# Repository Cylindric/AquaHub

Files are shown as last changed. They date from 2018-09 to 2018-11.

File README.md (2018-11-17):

# AquaHub
FOSSA Status (https://app.fossa.io/projects/git%2Bgithub.com%2FCylindric%2FAquaHub?ref=badge_shield)


# Key Components

## Hardware

The electronic designs are all made using [KiCad](http://kicad-pcb.org).

The actual KiCad project files are [here](Hardware/AquaHub/).

Rendered output (schematic and board PDFs, gerbers and bom) are [here](Hardware/Output/). (Not always up-to-date with the schematics and boards, so use with caution)

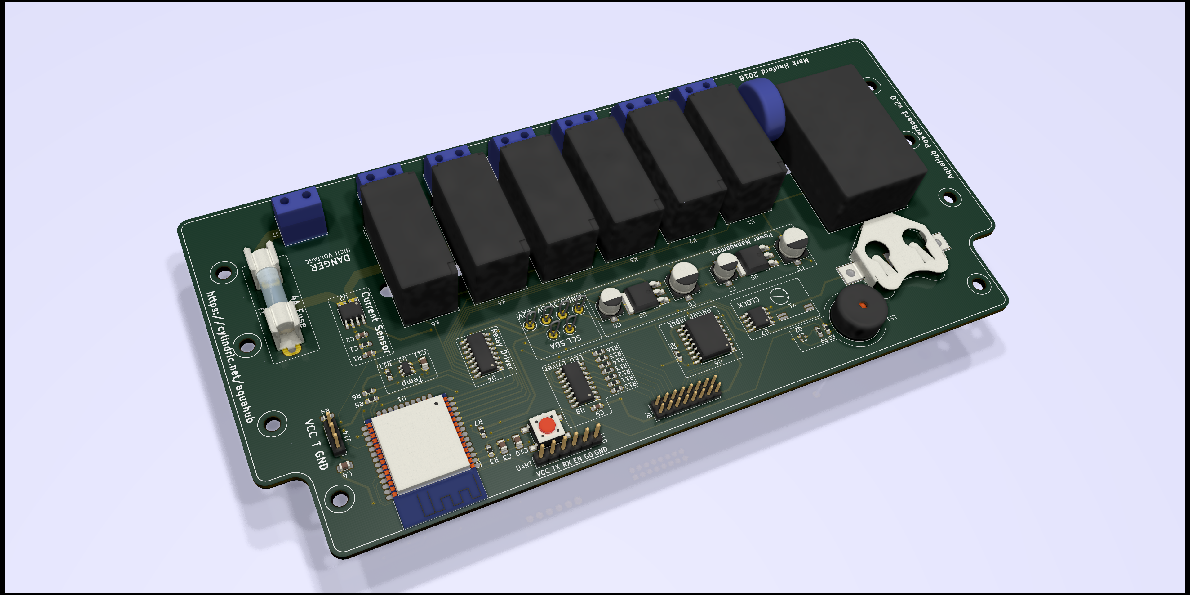
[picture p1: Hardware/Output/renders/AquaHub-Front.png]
Open Hardware


### License

All hardware designs are licensed under the [CERN Open Hardware Licence v1.2](https://www.ohwr.org/licenses/cern-ohl/license_versions/v1.2).

Myriam Ayass, legal adviser of the Knowledge and Technology Transfer Group at CERN and author of the CERN OHL:

> In the spirit of knowledge sharing and dissemination, the CERN Open Hardware Licence (CERN OHL) governs the use, copying, modification and distribution of hardware design documentation, and the manufacture and distribution of products.
> 
> The CERN–OHL is to hardware what the General Public Licence (GPL) is to software. It defines the conditions under which a licensee will be able to use or modify the licensed material. The concept of ‘open-source hardware’ or ‘open hardware’ is not yet as well known or widespread as the free software or open-source software concept. However, it shares the same principles: anyone should be able to see the source (the design documentation in case of hardware), study it, modify it and share it.
> 
> In addition, if modifications are made and distributed, it must be under the same licence conditions – this is the ‘persistent’ nature of the licence, which ensures that the whole community will continue benefiting from improvements, in the sense that everyone will in turn be able to make modifications to these improvements.

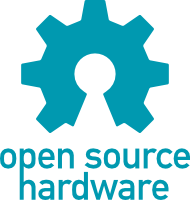
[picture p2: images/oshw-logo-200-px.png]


### Rev 1
- [x] ESP32 module for control and wireless access (Espressif ESP32-WROOM-32D)
- [x] Current Sensing for consumption reporting and equipment failure detection (Melexis MLX91210KDC)
- [x] RTC for power-loss schedule persistence (Maxim DS1307Z)
- [x] Temperature monitoring (DS18B20)
- [x] Audible alarm
- [x] Six switchable mains-level outputs (Fujitsu FTR-F1A)
- [x] Direct mains-powered (Recom RAC04-12SGB)

### Rev 2
- [ ] PCB: selectable low-level power select, for testing from a 12V supply instead of 240V
- [x] PCB: additional sensor for ambient temperature (on-board or external?)
- [ ] PCB: additional input for flow-rate sensor
- [ ] PCB: additional input for pH sensor (might not be feasible without a permanent-immersion sensor?)
- [ ] PCB: LED power indication for ESP
- [x] PCB: Reset button for ESP
- [x] PCB: Test points for probe hooks
- [x] PCB: Change buttons to off-board panel buttons
- [ ] ENCLOSURE: Add a 6-pin socket for programming
- [ ] ENCLOSURE: Switched & fused power inlet receptacle
- [ ] ENCLOSURE: Non-PCB panel buttons - more choice, better buttons
- [ ] ENCLOSURE: Power LED

## Software

### License

All software (firmware) are Copyright 2018 Mark Hanford and licensed under the [Apache License, Version 2.0](http://www.apache.org/licenses/LICENSE-2.0) (the "License");

> You may not use this file except in compliance with the License. You may obtain a copy of the License at
>
> http://www.apache.org/licenses/LICENSE-2.0
>
> Unless required by applicable law or agreed to in writing, software distributed under the License is distributed on an "AS IS" BASIS, WITHOUT WARRANTIES OR CONDITIONS OF ANY KIND, either express or implied.
> See the License for the specific language governing permissions and limitations under the License.

### Rev 1
- [ ] Over-the-air firmware updates
- [ ] Web UI
- [ ] Task Scheduler
- [ ] Temperature-based control
- [ ] Temperature alarm
- [ ] Pump-fail alarm
- [ ] WiFi config

# Hardware Build

A Mouser project with some of the components listed in detail is available here: [AquaHub At Mouser](https://www.mouser.com/ProjectManager/ProjectDetail.aspx?AccessID=329311b4a5). Not always updated with the current BOM from the schematic, and parts change so may be unavailable. CHECK THE SCHEMATIC.

## Datasheets

* [Espressif ESP32 WROOM 32D](https://www.espressif.com/sites/default/files/documentation/esp32-wroom-32d_esp32-wroom-32u_datasheet_en.pdf)
* [Recom 5v Regulator](https://www.recom-power.com/pdf/Innoline/R-78Exx-0.5.pdf)
* [Diodes 3.3V Regulator](http://www.diodes.com/datasheets/AP1117.pdf)
* [2SC1815 Transistor](https://media.digikey.com/pdf/Data%20Sheets/Toshiba%20PDFs/2SC1815.pdf)
* [Maxim I²C RTC](https://datasheets.maximintegrated.com/en/ds/DS1307.pdf)
* [TI I²C IO Expander](http://www.ti.com/lit/ds/symlink/tca9534.pdf)
* [TI I²C LED Driver](http://www.ti.com/lit/ds/symlink/tpic2810.pdf)

## References

* DS18B20 temperature - [ESP32 With Multiple DS18B20 Sensors](https://randomnerdtutorials.com/esp32-with-multiple-ds18b20-temperature-sensors/)

# Attribution

* Fish icon is from [iconsDB](https://www.iconsdb.com/custom-color/fish-3-icon.html); Creative Commons Attribution-NoDerivs 3.0.

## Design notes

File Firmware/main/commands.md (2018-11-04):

# Serial Commands

## relay

* relay on n
* relay off n

## time

* time get
* time set

## i2c

* i2c

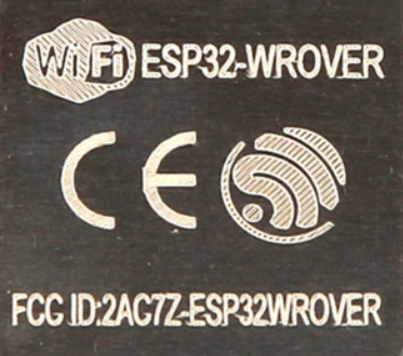
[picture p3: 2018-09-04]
Hardware/AquaHub/Models/esp32-wrover.PNG

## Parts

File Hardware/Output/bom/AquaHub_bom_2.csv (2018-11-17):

Component | Description | Part | References | Value | Footprint | Quantity Per PCB | Datasheet | Mouser | Vendor | Farnell | RS
1 | b'' | b'Battery_Cell-Device' | b'BT1' | b'CR2032' | b'BatteryHolder_Multicomp_BC-2001_1x2032' | b'1' | b'~' | b'534-1058' | b'Mouser' | b'' | b''
2 | b'' | b'C_Small-Device' | b'C4 C10 C11' | b'0.1uF' | b'C_0805_2012Metric_Pad1.15x1.40mm_HandSolder' | b'3' | b'~' | b'TAJB106K006SNJ' | b'Mouser' | b'' | b''
3 | b'' | b'C-Device' | b'C1' | b'100nF' | b'C_0603_1608Metric_Pad1.05x0.95mm_HandSolder' | b'1' | b'~' | b'710-885012206071' | b'Mouser' | b'CA07658' | b''
4 | b'Unpolarized capacitor, small symbol' | b'C_Small' | b'C9' | b'100nF' | b'C_0603_1608Metric_Pad1.05x0.95mm_HandSolder' | b'1' | b'~' | b'710-885012206071' | b'' | b'CA07658' | b''
5 | b'' | b'C-Device' | b'C2' | b'10nF' | b'C_0603_1608Metric_Pad1.05x0.95mm_HandSolder' | b'1' | b'~' | b'VJ0603A102GXAPW1BC' | b'Mouser' | b'' | b''
6 | b'' | b'C_Small-Device' | b'C3' | b'10uF' | b'C_0805_2012Metric_Pad1.15x1.40mm_HandSolder' | b'1' | b'~' | b'TAJB106K006SNJ' | b'Mouser' | b'' | b''
7 | b'' | b'CP_Small-Device' | b'C5 C6' | b'10uF' | b'CP_Elec_6.3x5.4_Nichicon' | b'2' | b'~' | b'UWX1H100MCL1GB' | b'Mouser' | b'CA07886' | b''
8 | b'' | b'CP_Small-Device' | b'C7 C8' | b'4.7uF' | b'CP_Elec_5x5.4' | b'2' | b'~' | b'UWX1H4R7MCL1GB' | b'Mouser' | b'' | b''
9 | b'' | b'Fuse-Device' | b'F1' | b'4A' | b'Fuseholder_Glass_5mmx20mm' | b'1' | b'~' | b'534-3512' | b'Mouser' | b'' | b''
10 | b'Generic connector, single row, 01x15, script generated (kicad-library-utils/schlib/autogen/connector/)' | b'Conn_01x15_Female' | b'J8' | b'Conn_01x15_Female' | b'PinHeader_2x08_P2.00mm_Vertical' | b'1' | b'https://www.mouser.co.uk/datasheet/2/185/DF51_catalog-1274968.pdf' | b'798-DF51A-16DP-2DSA' | b'' | b'' | b''
11 | b'' | b'Conn_01x03-Connector_Generic' | b'J14' | b'PinHeader3' | b'PinHeader_1x03_P2.54mm_Vertical' | b'1' | b'~' | b'710-61300311121' | b'' | b'' | b''
12 | b'' | b'Conn_01x06-Connector_Generic' | b'J10' | b'PinHeader6' | b'PinHeader_1x06_P2.54mm_Vertical' | b'1' | b'~' | b'710-61300611121' | b'' | b'' | b''
13 | b'' | b'Screw_Terminal_01x02-Connector' | b'J1 J2 J3 J4 J5 J6 J7' | b'Screw_Terminal_01x02' | b'TerminalBlock_Phoenix_PT-1,5-2-5.0-H_1x02_P5.00mm_Horizontal' | b'7' | b'~' | b'1935161' | b'Mouser' | b'' | b''
14 | b'' | b'Fujitsu_FTR-F1A-Relay' | b'K1 K2 K3 K4 K5 K6' | b'5A Relay' | b'Relay_DPST_Fujitsu_FTR-F1A' | b'6' | b'' | b'FTR-F1AA012V' | b'Mouser' | b'' | b''
15 | b'Crystal speaker/transducer' | b'Speaker_Crystal' | b'LS1' | b'Piezo' | b'Buzzer_TDK_PS1240P02BT_D12.2mm_H6.5mm' | b'1' | b'~' | b'PS1240P02BT' | b'Mouser' | b'' | b''
16 | b'' | b'2SC1815-Transistor_BJT' | b'Q2' | b'2SC4738' | b'SOT-416' | b'1' | b'http://www.semicon.toshiba.co.jp/info/lookup.jsp?pid=2SC4738&lang=en' | b'757-2SC4738-YLF' | b'Mouser' | b'SC06581' | b''
17 | b'Resistor' | b'R' | b'R17' | b'1.5k' | b'R_0603_1608Metric_Pad1.05x0.95mm_HandSolder' | b'1' | b'~' | b'603-RC0603FR-101K5L' | b'Mouser' | b'' | b''
18 | b'' | b'R-Device' | b'R1 R3 R7' | b'10k' | b'R_0603_1608Metric_Pad1.05x0.95mm_HandSolder' | b'3' | b'~' | b'603-RC0603FR-0710KL' | b'Mouser' | b'' | b''
19 | b'' | b'R-Device' | b'R8 R9' | b'1K' | b'R_0603_1608Metric_Pad1.05x0.95mm_HandSolder' | b'2' | b'~' | b'603-RC0603FR-071KL' | b'Mouser' | b'RE07090' | b''
20 | b'' | b'R-Device' | b'R10 R11 R12 R13 R14 R15 R16' | b'330R' | b'R_0603_1608Metric_Pad1.05x0.95mm_HandSolder' | b'7' | b'~' | b'603-RC0603FR-07330RL' | b'Mouser' | b'RE07105' | b''
21 | b'Resistor' | b'R' | b'R2 R4' | b'4.7k' | b'R_0603_1608Metric_Pad1.05x0.95mm_HandSolder' | b'2' | b'~' | b'603-RC0603FR-074K7L' | b'Mouser' | b'' | b''
22 | b'' | b'R-Device' | b'R5 R6' | b'4.7k' | b'R_0603_1608Metric_Pad1.05x0.95mm_HandSolder' | b'2' | b'~' | b'603-RC0603FR-074K7L' | b'Mouser' | b'' | b''
23 | b'' | b'Varistor-Device' | b'RV1' | b'S14MOV' | b'RV_Disc_D15.5mm_W6.1mm_P7.5mm' | b'1' | b'~' | b'B72214P2251K101' | b'Mouser' | b'' | b''
24 | b'' | b'SW_CK_D6R_SPST-Switch' | b'SW7' | b'Reset' | b'SW_SPST_PTS645' | b'1' | b'' | b'611-PTS645SM43SMTR92' | b'Mouser' | b'' | b''
25 | b'' | b'NCP1117-3.3_TO252-Regulator_Linear' | b'U3' | b'1A 3.3V' | b'TO-252-3_TabPin2' | b'1' | b'http://www.diodes.com/datasheets/AP1117.pdf' | b'NCP1117DT33G' | b'Mouser' | b'' | b''
26 | b'' | b'NCP1117-5.0_TO252-Regulator_Linear' | b'U5' | b'1A 5V' | b'TO-252-3_TabPin2' | b'1' | b'https://www.recom-power.com/pdf/Innoline/R-78Exx-0.5.pdf' | b'NCP1117DT50G' | b'Mouser' | b'' | b''
27 | b'' | b'DS1307+-Timer_RTC' | b'U7' | b'DS1307+' | b'SOIC-8_3.9x4.9mm_P1.27mm' | b'1' | b'https://datasheets.maximintegrated.com/en/ds/DS1307.pdf' | b'700-DS1307ZT&R' | b'' | b'' | b''
28 | b'' | b'ESP32-WROOM-32-MCU_Espressif' | b'U1' | b'ESP32-WROOM' | b'Espressif_ESP32_WROOM_32_SMT' | b'1' | b'' | b'ESP32-WROOM-32D' | b'Mouser' | b'' | b''
29 | b'' | b'MLX91210-AquaParts' | b'U2' | b'MLX91210' | b'SOIC-8_3.9x4.9mm_P1.27mm' | b'1' | b'http://www.allegromicro.com/~/media/Files/Datasheets/ACS723-Datasheet.ashx?la=en' | b'MLX91210KDC-CAS-102-SP' | b'Mouser' | b'' | b''
30 | b' Digital Temperature Sensor & Thermal Watchdog, SOIC-8 and VSSOP-8' | b'PCT2075-TSOP6' | b'U9' | b'PCT2075' | b'TSOP-6_1.65x3.05mm_P0.95mm' | b'1' | b'https://www.mouser.co.uk/datasheet/2/302/PCT2075-1127732.pdf' | b'771-PCT2075GVX' | b'' | b'' | b''
31 | b'' | b'TCA9534-Interface_Expansion' | b'U6' | b'TCA9534' | b'SOIC-16W_7.5x10.3mm_P1.27mm' | b'1' | b'http://www.ti.com/lit/ds/symlink/tca9534.pdf' | b'TCA9534DWR' | b'Mouser' | b'' | b''
32 | b'8-bit LED driver with I2C interface' | b'TPIC2810D' | b'U8' | b'TPIC2810D' | b'SOIC-16_3.9x9.9mm_P1.27mm' | b'1' | b'http://www.ti.com/lit/ds/symlink/tpic2810.pdf' | b'595-TPIC2810DR' | b'' | b'' | b'660-7981'
33 | b'' | b'TPL7407LA-AquaParts' | b'U4' | b'TPL7407LADR' | b'SOIC-16_3.9x9.9mm_P1.27mm' | b'1' | b'http://www.ti.com/lit/ds/symlink/tpl7407la.pdf' | b'595-TPL7407LADR' | b'Mouser' | b'' | b''
34 | b'' | b'RAC04-xxGA-Converter_ACDC' | b'V1' | b'4W AC-DC Converter' | b'Converter_ACDC_RECOM_RAC04-xxSGx_THT' | b'1' | b'' | b'RAC04-12SGB' | b'' | b'' | b''
35 | b'Four pin crystal, GND on pins 2 and 3' | b'Crystal_GND23' | b'Y1' | b'32.768KHz' | b'Crystal_SMD_SeikoEpson_MC146-4Pin_6.7x1.5mm_HandSoldering' | b'1' | b'~' | b'732-MC146-32.7KAA0R' | b'' | b'' | b''
Component Groups: | 35
Component Count: | 61
Fitted Components: | 61
Number of PCBs: | 1
Total components: | 61
Schematic Version: | 2
Schematic Date: | 2018-08-28
BoM Date: | b'17/11/2018 01:01:26'
Schematic Source: | b'D:\\AquaHub\\Hardware\\AquaHub\\AquaHub.sch'
KiCad Version: | b'Eeschema (6.0.0-rc1-dev-904-g29e0e6921)'

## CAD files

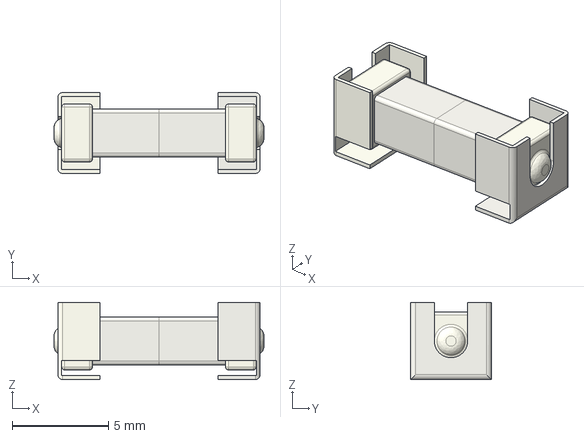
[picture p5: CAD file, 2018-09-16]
Hardware/AquaHub/Models/Fuse.step
10.9 x 4.20 x 4.00 mm

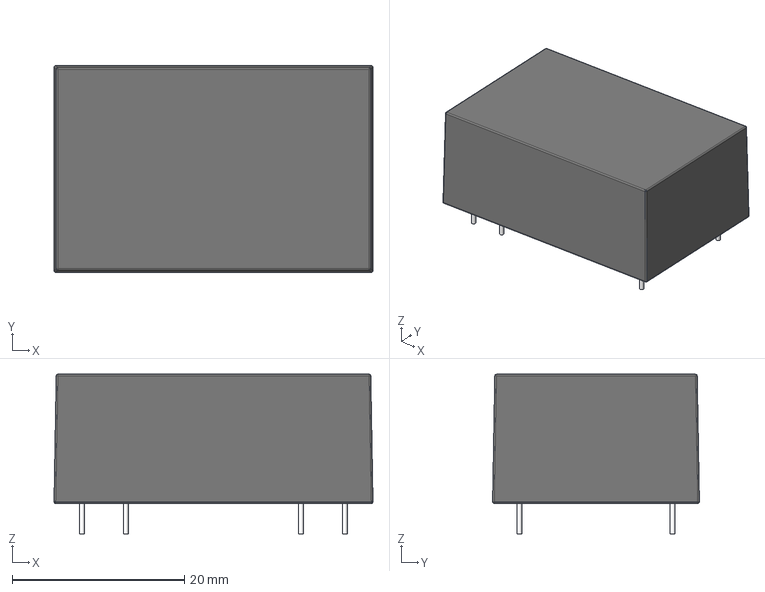
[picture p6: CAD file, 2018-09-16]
Hardware/AquaHub/Models/Recom RAC04-GA.step
37.0 x 24.0 x 18.5 mm

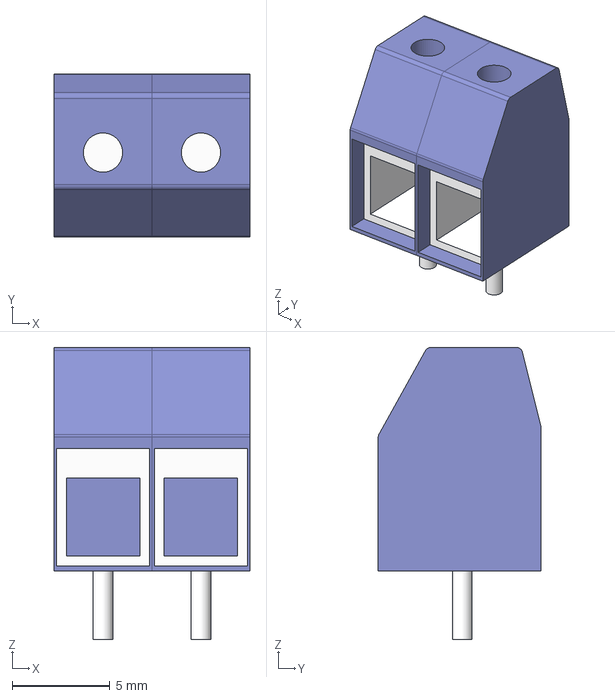
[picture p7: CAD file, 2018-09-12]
Hardware/AquaHub/Models/phoenix_pt-1.5-2.step
10.0 x 8.30 x 14.9 mm
Cage x 2

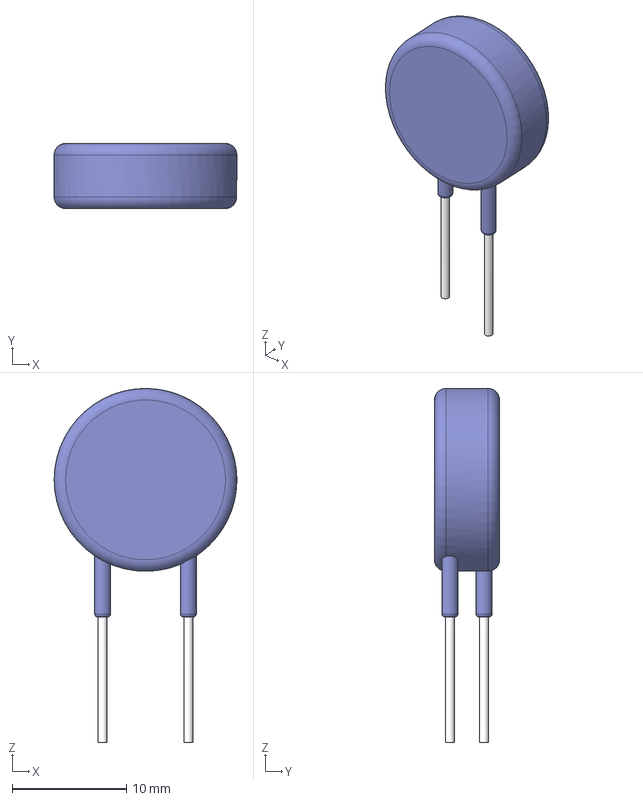
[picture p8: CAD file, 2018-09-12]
Hardware/AquaHub/Models/Varistor.step
16.0 x 5.70 x 31.0 mm

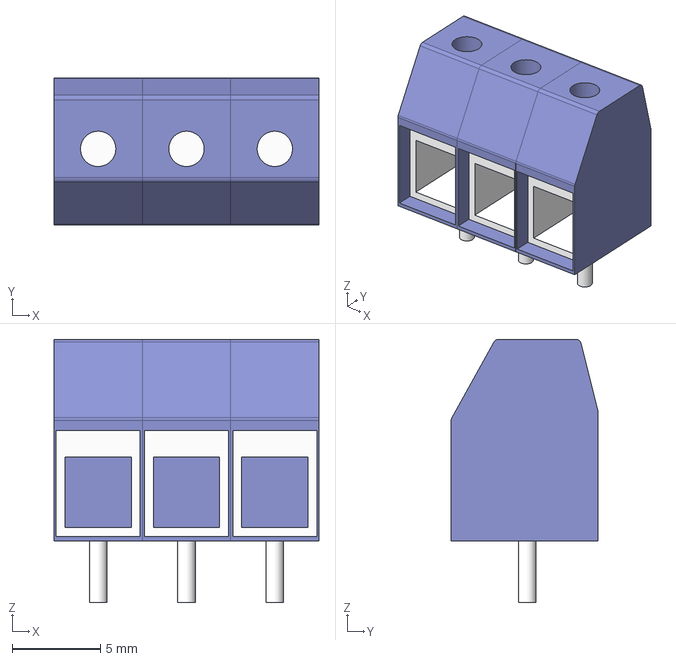
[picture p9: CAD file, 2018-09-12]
Hardware/AquaHub/Models/phoenix_pt-1.5-3.step
15.0 x 8.30 x 14.9 mm
Cage x 3

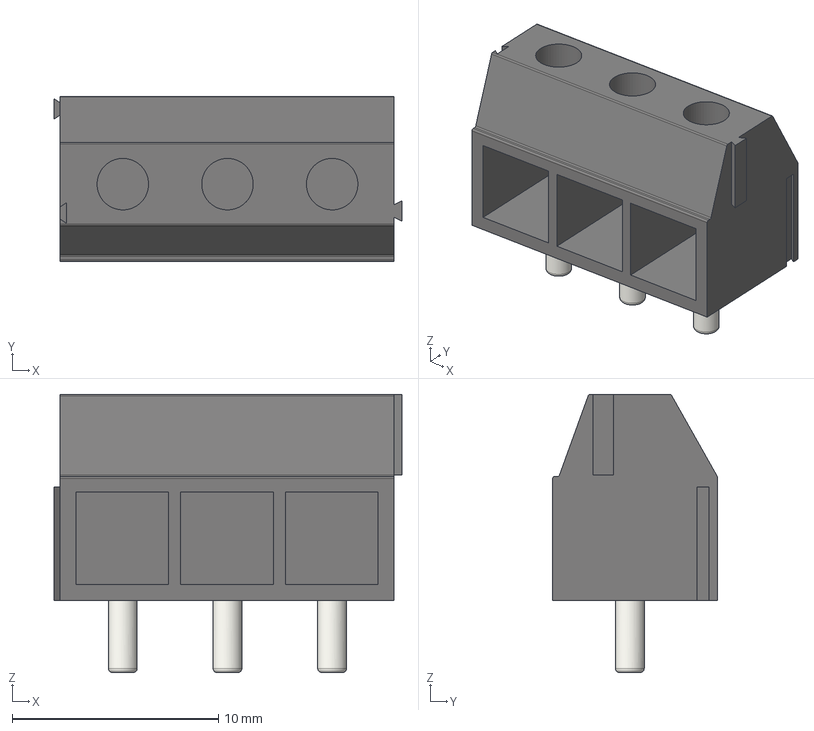
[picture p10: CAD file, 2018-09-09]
Hardware/AquaHub/Models/weidmuller_pm_5_08_3_way.step
16.9 x 8.00 x 13.5 mm

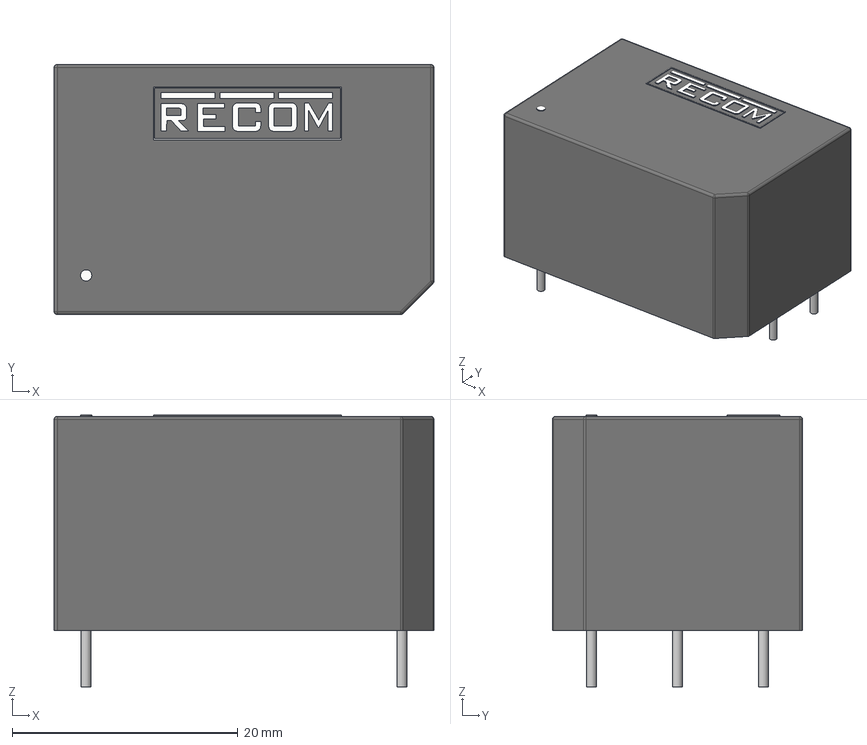
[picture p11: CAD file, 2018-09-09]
Hardware/AquaHub/Models/Converter_ACDC_RECOM_RAC01-xSGB_THT.step
33.7 x 22.2 x 24.1 mm

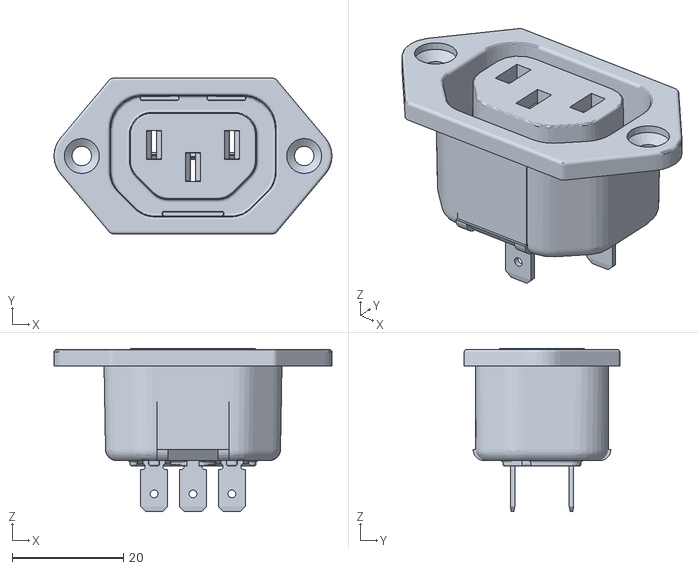
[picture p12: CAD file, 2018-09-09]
Hardware/AquaHub/Models/socket-c13.obj
50.0 x 28.0 x 29.4

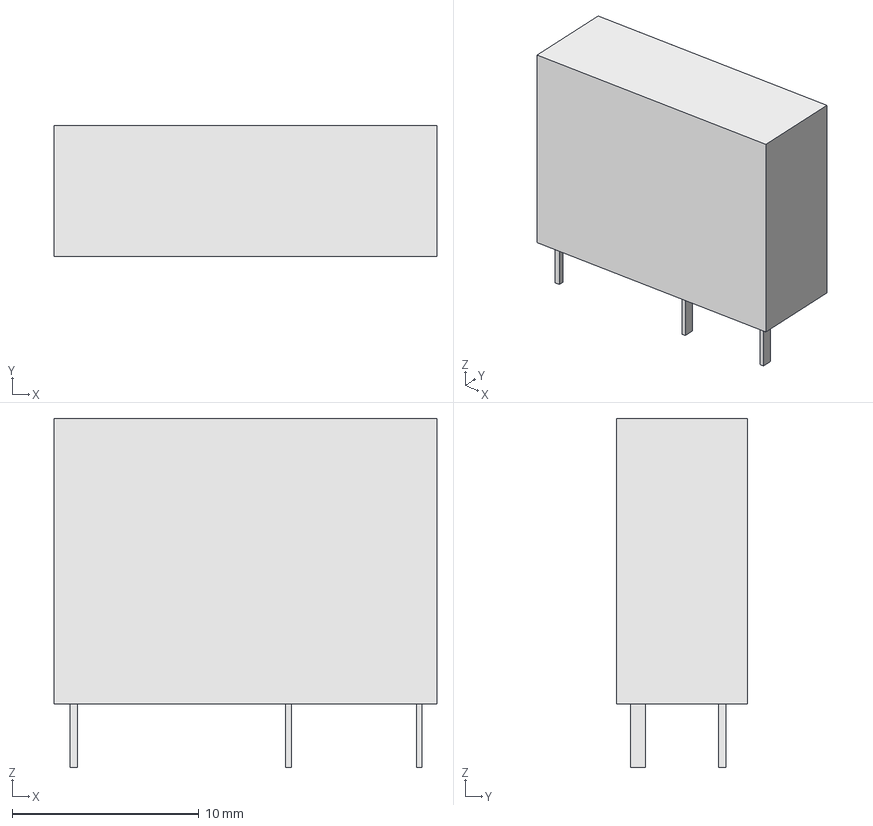
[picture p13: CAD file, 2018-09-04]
Hardware/AquaHub/Models/Relay-HF46F.FCStd
20.5 x 7.00 x 18.7 mm

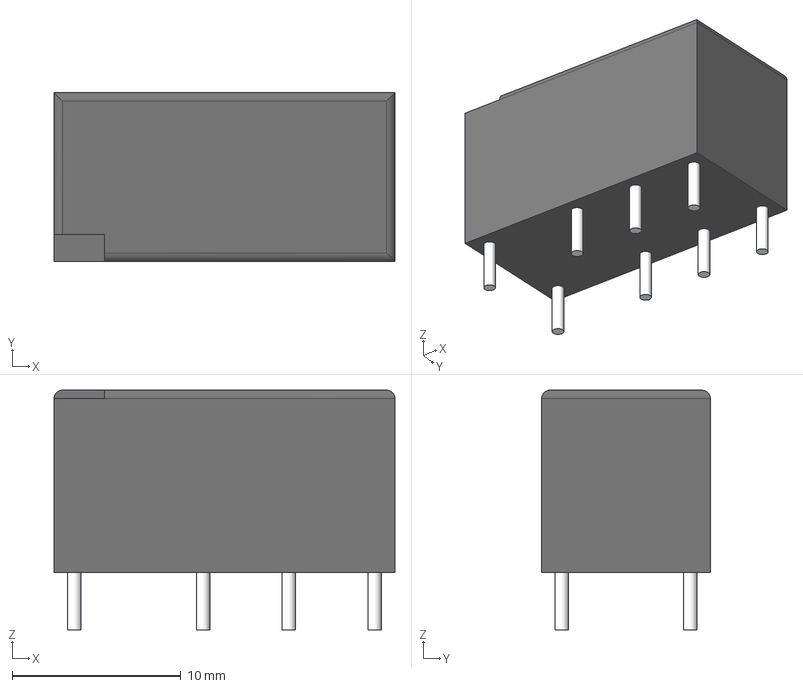
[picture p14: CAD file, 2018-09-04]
Hardware/AquaHub/Models/MT2 Relay.step
20.2 x 10.0 x 14.2 mm

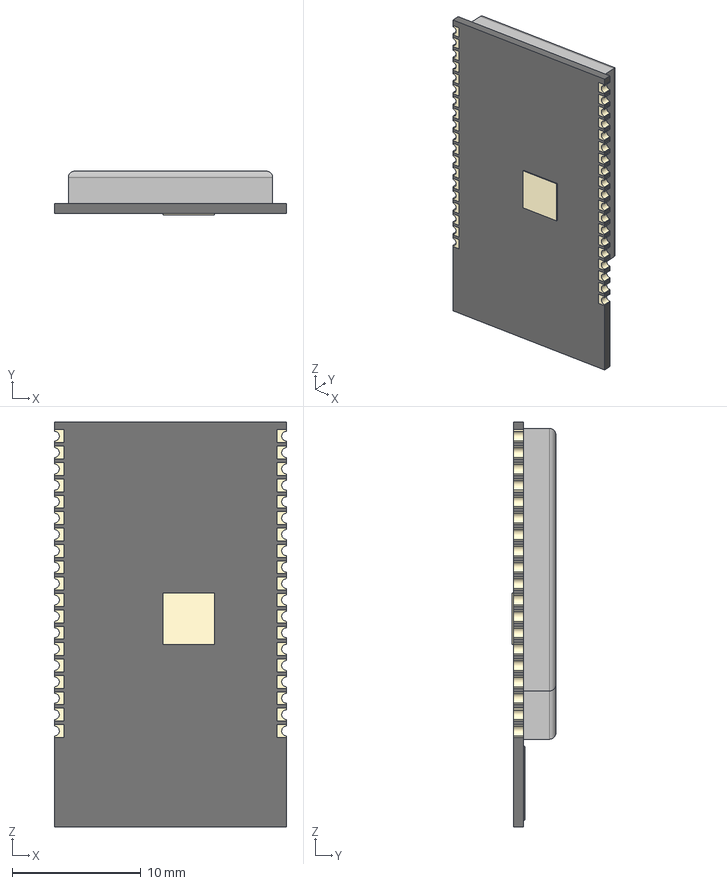
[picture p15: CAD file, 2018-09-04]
Hardware/AquaHub/Models/ES32-WROVER.step
18.0 x 3.40 x 31.4 mm

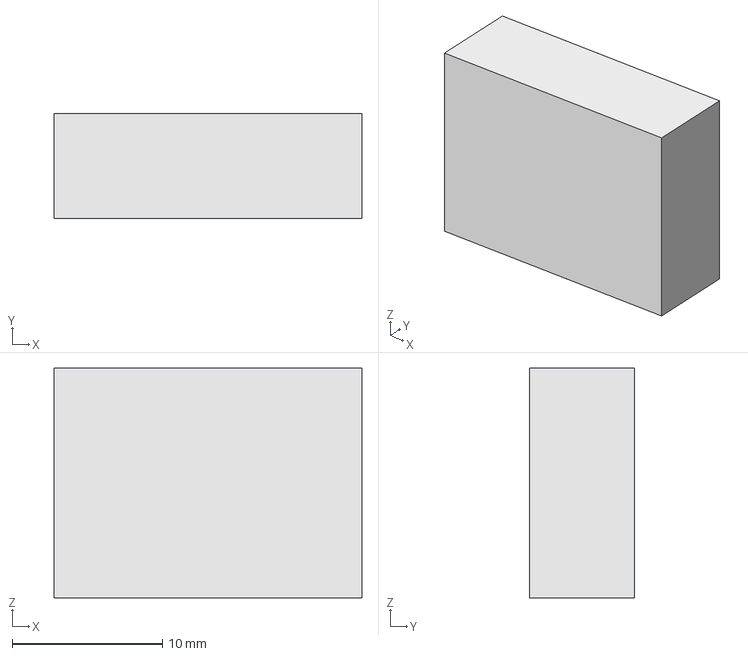
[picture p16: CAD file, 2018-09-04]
Hardware/AquaHub/Models/Cube.step
20.5 x 7.00 x 15.3 mm

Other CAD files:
Hardware/AquaHub/Models/Recom RAC01-GB.step
Hardware/AquaHub/Models/Compound.step
Hardware/AquaHub/Models/Recom_RAC01-GB.step

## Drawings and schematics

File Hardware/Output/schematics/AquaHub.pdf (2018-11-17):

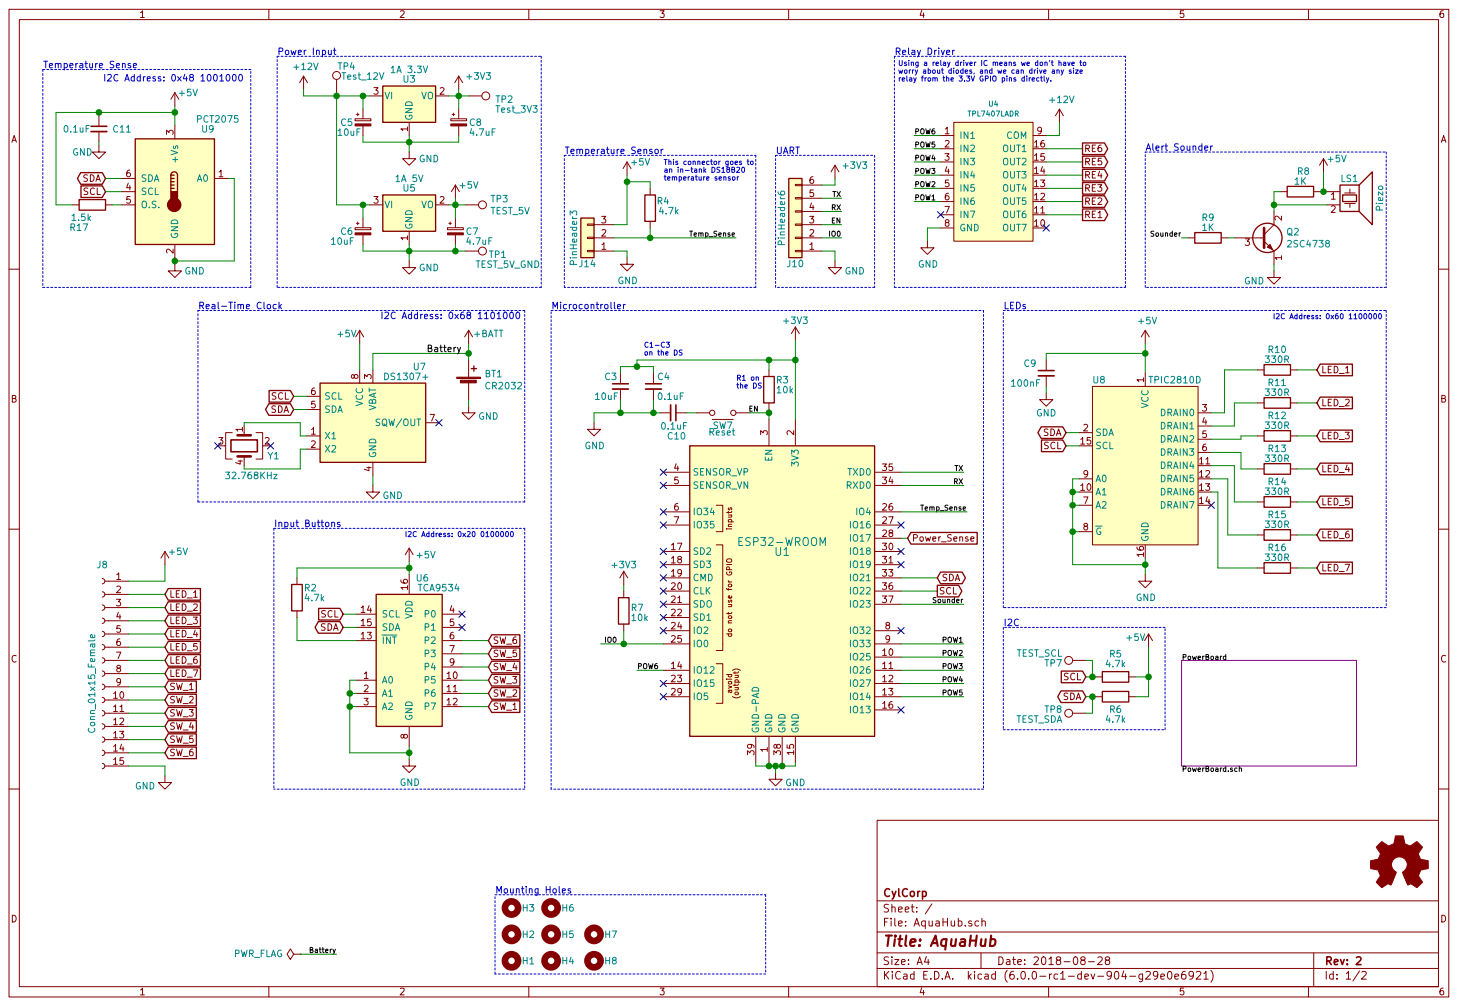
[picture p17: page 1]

Using a relay driver IC means we don't have to worry about diodes, and we can drive any size

Temp_Sense This connector goes to
an in-tank DS18B20

4 SDA 5 SCL 6 SQW/OUT 7 VCC

File: AquaHub.sch Sheet: / CylCorp

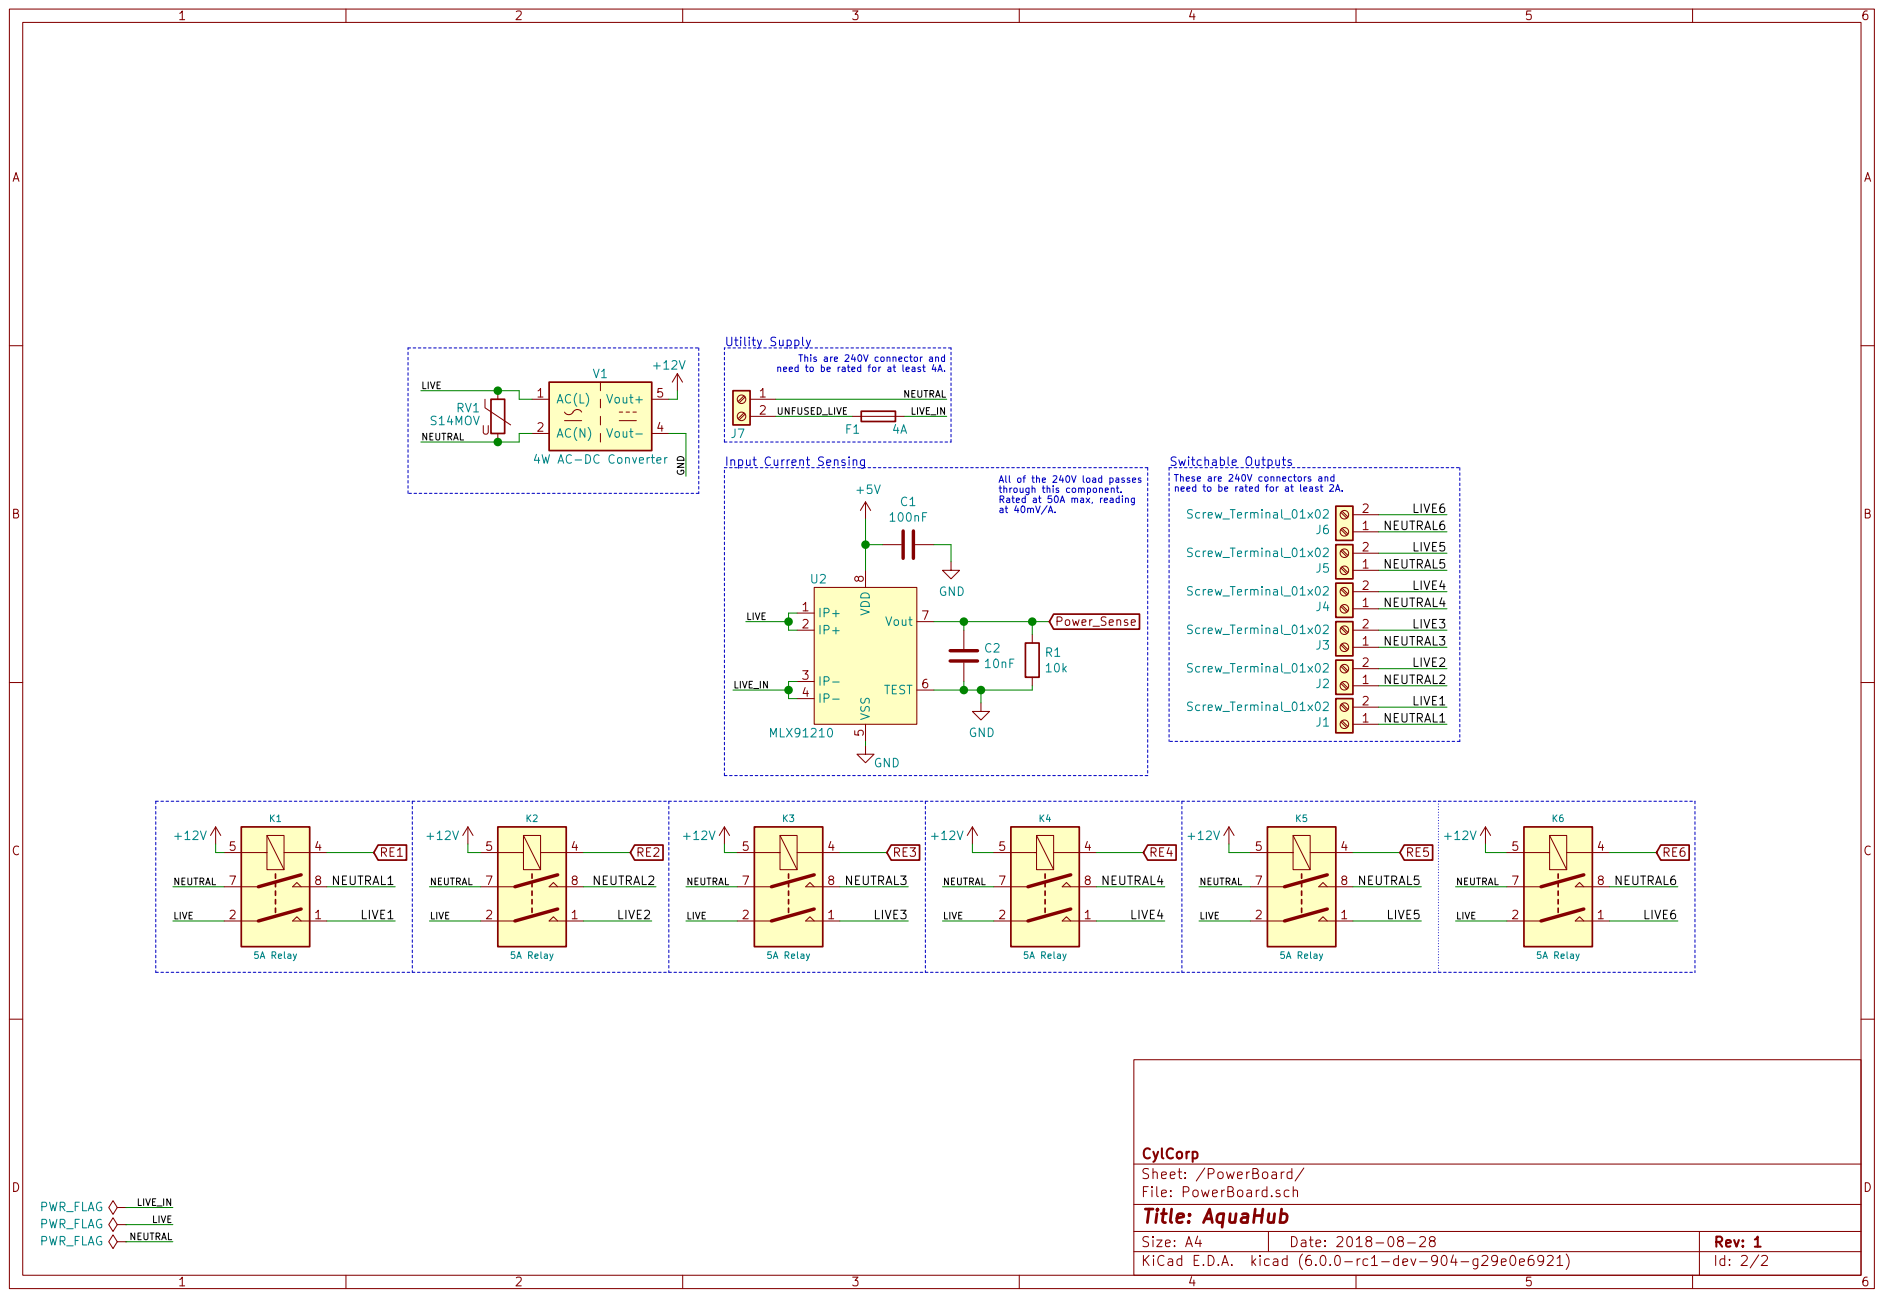
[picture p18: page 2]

This are 240V connector and

These are 240V connectors and

All of the 240V load passes
through this component. Rated at 50A max, reading

File: PowerBoard.sch Sheet: /PowerBoard/ CylCorp

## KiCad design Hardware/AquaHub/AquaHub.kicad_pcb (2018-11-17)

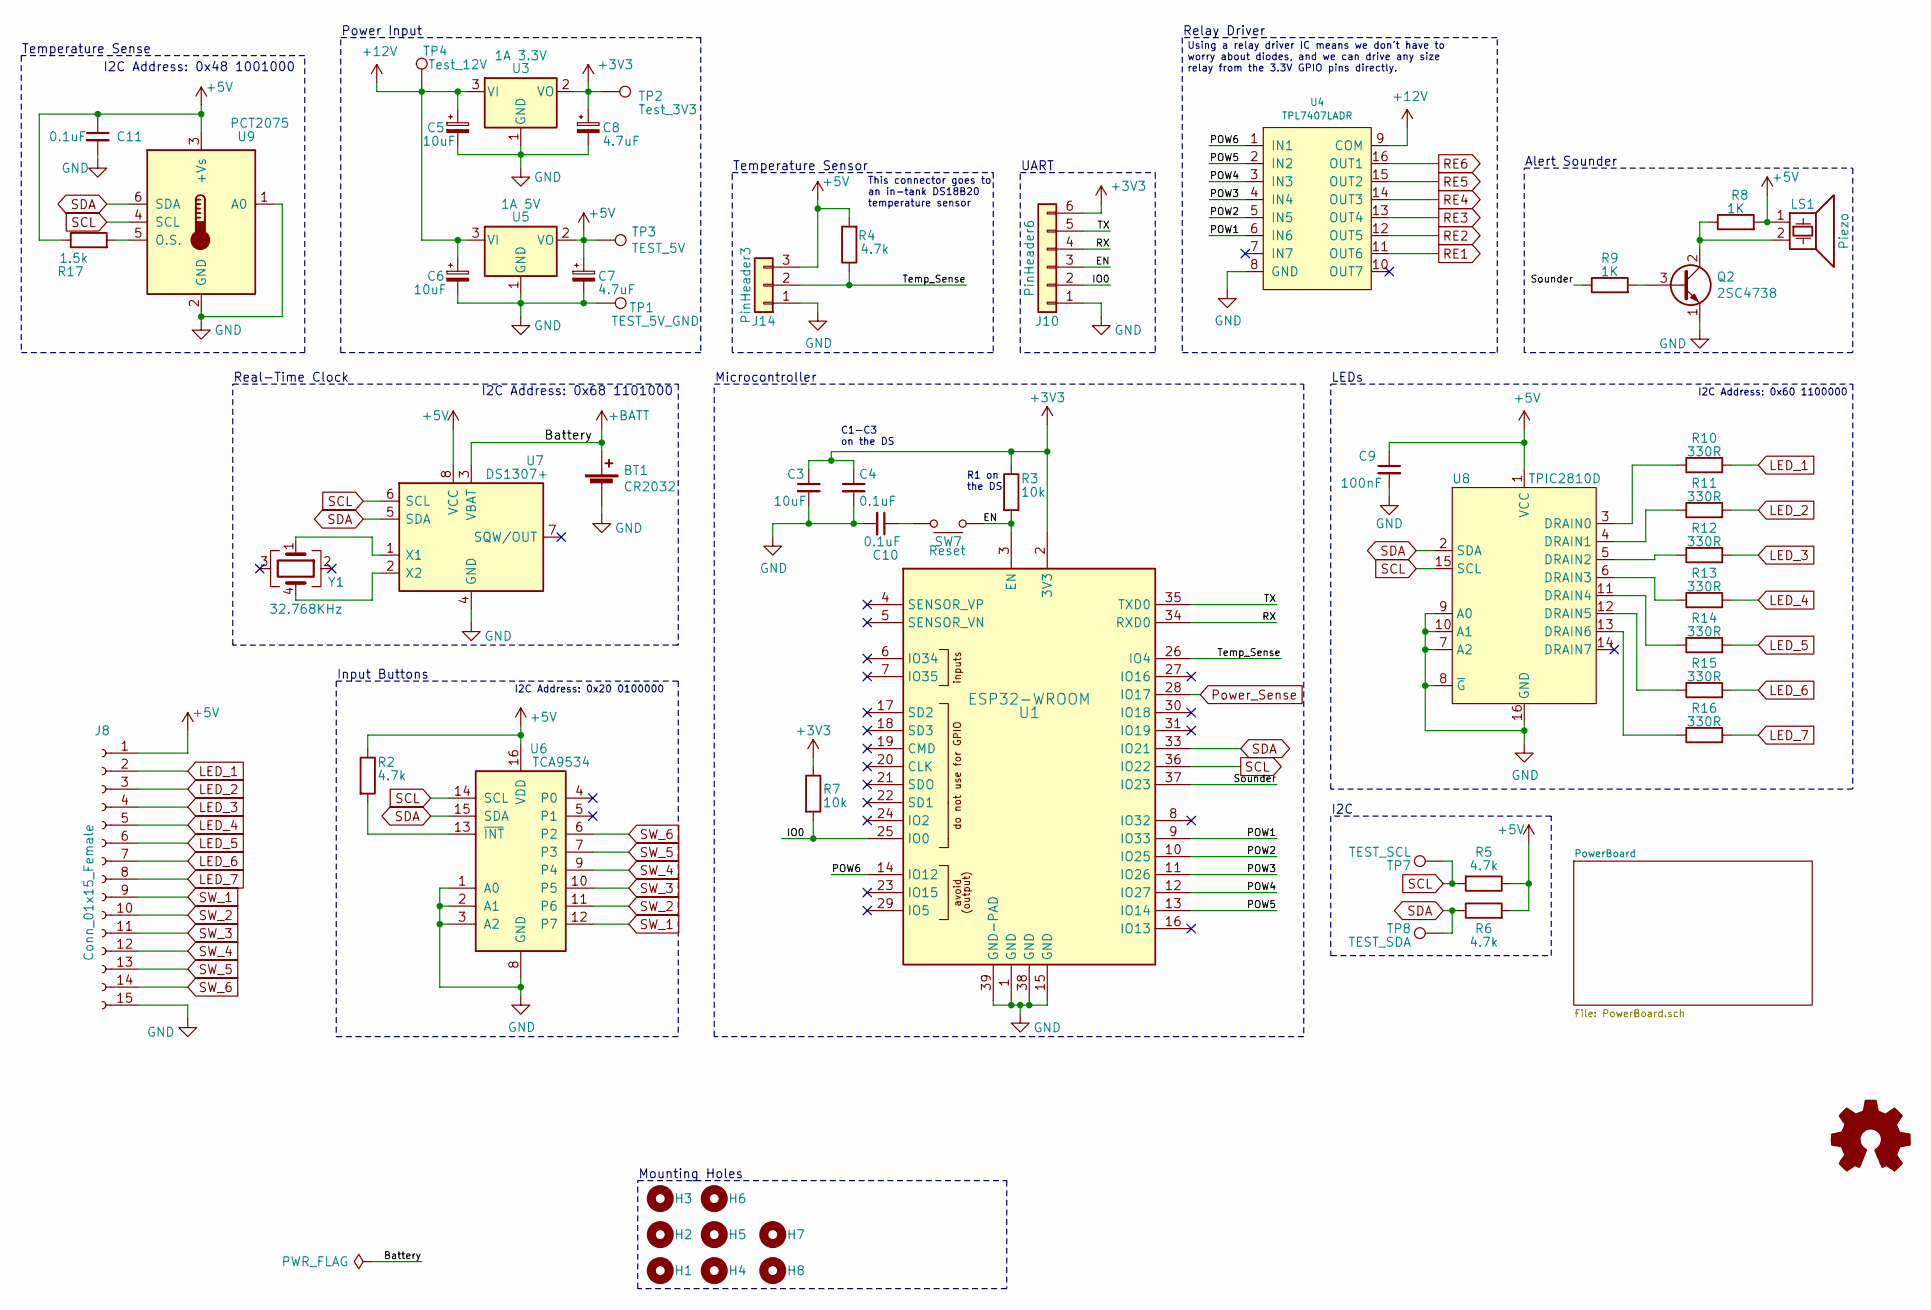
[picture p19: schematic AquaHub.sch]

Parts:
BT1: CR2032; BatteryHolder_Multicomp_BC-2001_1x2032; Mouser 534-1058
C3: 10uF; C_0805_2012Metric_Pad1.15x1.40mm_HandSolder; Mouser TAJB106K006SNJ
C4, C10, C11: 0.1uF; C_0805_2012Metric_Pad1.15x1.40mm_HandSolder; Mouser TAJB106K006SNJ
C5, C6: 10uF; CP_Elec_6.3x5.4_Nichicon; Farnell CA07886
C7, C8: 4.7uF; CP_Elec_5x5.4; Mouser UWX1H4R7MCL1GB
C9: 100nF; C_0603_1608Metric_Pad1.05x0.95mm_HandSolder; Farnell CA07658
H1, H2, H3, H4, H5, H6, H7, H8: MountingHole; MountingHole_3.2mm_M3
J8: Conn_01x15_Female; PinHeader_2x08_P2.00mm_Vertical; Mouser 798-DF51A-16DP-2DSA
J10: PinHeader6; PinHeader_1x06_P2.54mm_Vertical; Mouser 710-61300611121
J14: PinHeader3; PinHeader_1x03_P2.54mm_Vertical; Mouser 710-61300311121
LS1: Piezo; Buzzer_TDK_PS1240P02BT_D12.2mm_H6.5mm; Mouser PS1240P02BT
Q2: 2SC4738; SOT-416; Farnell SC06581
R2, R4, R5, R6: 4.7k; R_0603_1608Metric_Pad1.05x0.95mm_HandSolder; Mouser 603-RC0603FR-074K7L
R3, R7: 10k; R_0603_1608Metric_Pad1.05x0.95mm_HandSolder; Mouser 603-RC0603FR-0710KL
R8, R9: 1K; R_0603_1608Metric_Pad1.05x0.95mm_HandSolder; Farnell RE07090
R10, R11, R12, R13, R14, R15, R16: 330R; R_0603_1608Metric_Pad1.05x0.95mm_HandSolder; Farnell RE07105
R17: 1.5k; R_0603_1608Metric_Pad1.05x0.95mm_HandSolder; Mouser 603-RC0603FR-101K5L
SW7: Reset; SW_SPST_PTS645; Mouser 611-PTS645SM43SMTR92
TP1: TEST_5V_GND; TestPoint_Loop_D2.50mm_Drill1.0mm
TP2: Test_3V3; TestPoint_Loop_D2.50mm_Drill1.0mm
TP3: TEST_5V; TestPoint_Loop_D2.50mm_Drill1.0mm
TP4: Test_12V; TestPoint_Loop_D2.50mm_Drill1.0mm
TP7: TEST_SCL; TestPoint_Loop_D2.50mm_Drill1.0mm
TP8: TEST_SDA; TestPoint_Loop_D2.50mm_Drill1.0mm
U1: ESP32-WROOM; Espressif_ESP32_WROOM_32_SMT; Mouser ESP32-WROOM-32D
U3: 1A 3.3V; TO-252-3_TabPin2; Mouser NCP1117DT33G
U4: TPL7407LADR; SOIC-16_3.9x9.9mm_P1.27mm; Mouser 595-TPL7407LADR
U5: 1A 5V; TO-252-3_TabPin2; Mouser NCP1117DT50G
U6: TCA9534; SOIC-16W_7.5x10.3mm_P1.27mm; Mouser TCA9534DWR
U7: DS1307+; SOIC-8_3.9x4.9mm_P1.27mm; Mouser 700-DS1307ZT&R
U8: TPIC2810D; SOIC-16_3.9x9.9mm_P1.27mm; Mouser 595-TPIC2810DR
U9: PCT2075; TSOP-6_1.65x3.05mm_P0.95mm; Mouser 771-PCT2075GVX
Y1: 32.768KHz; Crystal_SMD_SeikoEpson_MC146-4Pin_6.7x1.5mm_HandSoldering; Mouser 732-MC146-32.7KAA0R

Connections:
+3V3: C3.1, C4.1, C8.1, J10.6, R3.1, R7.1, TP2.1, U1.2 (3V3), U3.2 (VO)
+5V: C7.1, C9.1, C11.1, J8.1, J14.3, LS1.1, R2.1, R4.2, R5.1, R6.2, R8.2, R17.1, TP3.1, U5.2 (VO), U6.16 (VDD), U7.8 (VCC), U8.1 (VCC), U9.3 (+Vs); also elsewhere on the board
+12V: C5.1, C6.1, TP4.1, U3.3 (VI), U4.9 (COM), U5.3 (VI); also elsewhere on the board
+BATT: BT1.1 (+), U7.3 (VBAT)
/EN: J10.3, R3.2, SW7.1 (A), SW7.3 (A), U1.3 (EN)
/IO0: J10.2, R7.2, U1.25 (IO0)
/POW1: U1.9 (IO33), U4.6 (IN6)
/POW2: U1.10 (IO25), U4.5 (IN5)
/POW3: U1.11 (IO26), U4.4 (IN4)
/POW4: U1.12 (IO27), U4.3 (IN3)
/POW5: U1.13 (IO14), U4.2 (IN2)
/POW6: U1.14 (IO12), U4.1 (IN1)
/RX: J10.4, U1.34 (RXD0)
/Sounder: R9.1, U1.37 (IO23)
/TX: J10.5, U1.35 (TXD0)
/Temp_Sense: J14.2, R4.1, U1.26 (IO4)
GND: BT1.2 (-), C3.2, C4.2, C5.2, C6.2, C7.2, C8.2, C9.2, C10.2, C11.2, J8.15, J10.1, J14.1, Q2.1 (E), TP1.1, U1.1 (GND), U1.15 (GND), U1.38 (GND), U1.39 (GND-PAD), U3.1 (GND), U4.8 (GND), U5.1 (GND), U6.1 (A0), U6.2 (A1), U6.3 (A2), U6.8 (GND), U7.4 (GND), U8.7 (A2), U8.8 (~G), U8.9 (A0), U8.10 (A1), U8.16 (GND), U9.1 (A0), U9.2 (GND); also elsewhere on the board
LED_1: J8.2, R10.2
LED_2: J8.3, R11.2
LED_3: J8.4, R12.2
LED_4: J8.5, R13.2
LED_5: J8.6, R14.2
LED_6: J8.7, R15.2
LED_7: J8.8, R16.2
unnamed: C10.1, SW7.2 (B), SW7.4 (B)
unnamed: LS1.2, Q2.2 (C), R8.1
unnamed: Q2.3 (B), R9.2
unnamed: R2.2, U6.13 (~INT~)
unnamed: R10.1, U8.3 (DRAIN0)
unnamed: R11.1, U8.4 (DRAIN1)
unnamed: R12.1, U8.5 (DRAIN2)
unnamed: R13.1, U8.6 (DRAIN3)
unnamed: R14.1, U8.11 (DRAIN4)
unnamed: R15.1, U8.12 (DRAIN5)
unnamed: R16.1, U8.13 (DRAIN6)
unnamed: R17.2, U9.5 (O.S.)
unnamed: U7.1 (X1), Y1.1
unnamed: U7.2 (X2), Y1.4
Power_Sense: U1.28 (IO17); also elsewhere on the board
RE1: U4.11 (OUT6); also elsewhere on the board
RE2: U4.12 (OUT5); also elsewhere on the board
RE3: U4.13 (OUT4); also elsewhere on the board
RE4: U4.14 (OUT3); also elsewhere on the board
RE5: U4.15 (OUT2); also elsewhere on the board
RE6: U4.16 (OUT1); also elsewhere on the board
SCL: R5.2, TP7.1, U1.36 (IO22), U6.14 (SCL), U7.6 (SCL), U8.15 (SCL), U9.4 (SCL)
SDA: R6.1, TP8.1, U1.33 (IO21), U6.15 (SDA), U7.5 (SDA), U8.2 (SDA), U9.6 (SDA)
SW_1: J8.9, U6.12 (P7)
SW_2: J8.10, U6.11 (P6)
SW_3: J8.11, U6.10 (P5)
SW_4: J8.12, U6.9 (P4)
SW_5: J8.13, U6.7 (P3)
SW_6: J8.14, U6.6 (P2)

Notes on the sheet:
UART
Power Input
Relay Driver
Temperature Sensor
This connector goes to an in-tank DS18B20 temperature sensor
Using a relay driver IC means we don't have to worry about diodes, and we can drive any size relay from the 3.3V GPIO pins directly.
Microcontroller
Alert Sounder
Real-Time Clock
I2C Address: 0x68 1101000
Mounting Holes
Input Buttons
LEDs
I2C Address: 0x60 1100000
I2C Address: 0x20 0100000
I2C
C1-C3 on the DS
R1 on the DS
I2C Address: 0x48 1001000
Temperature Sense

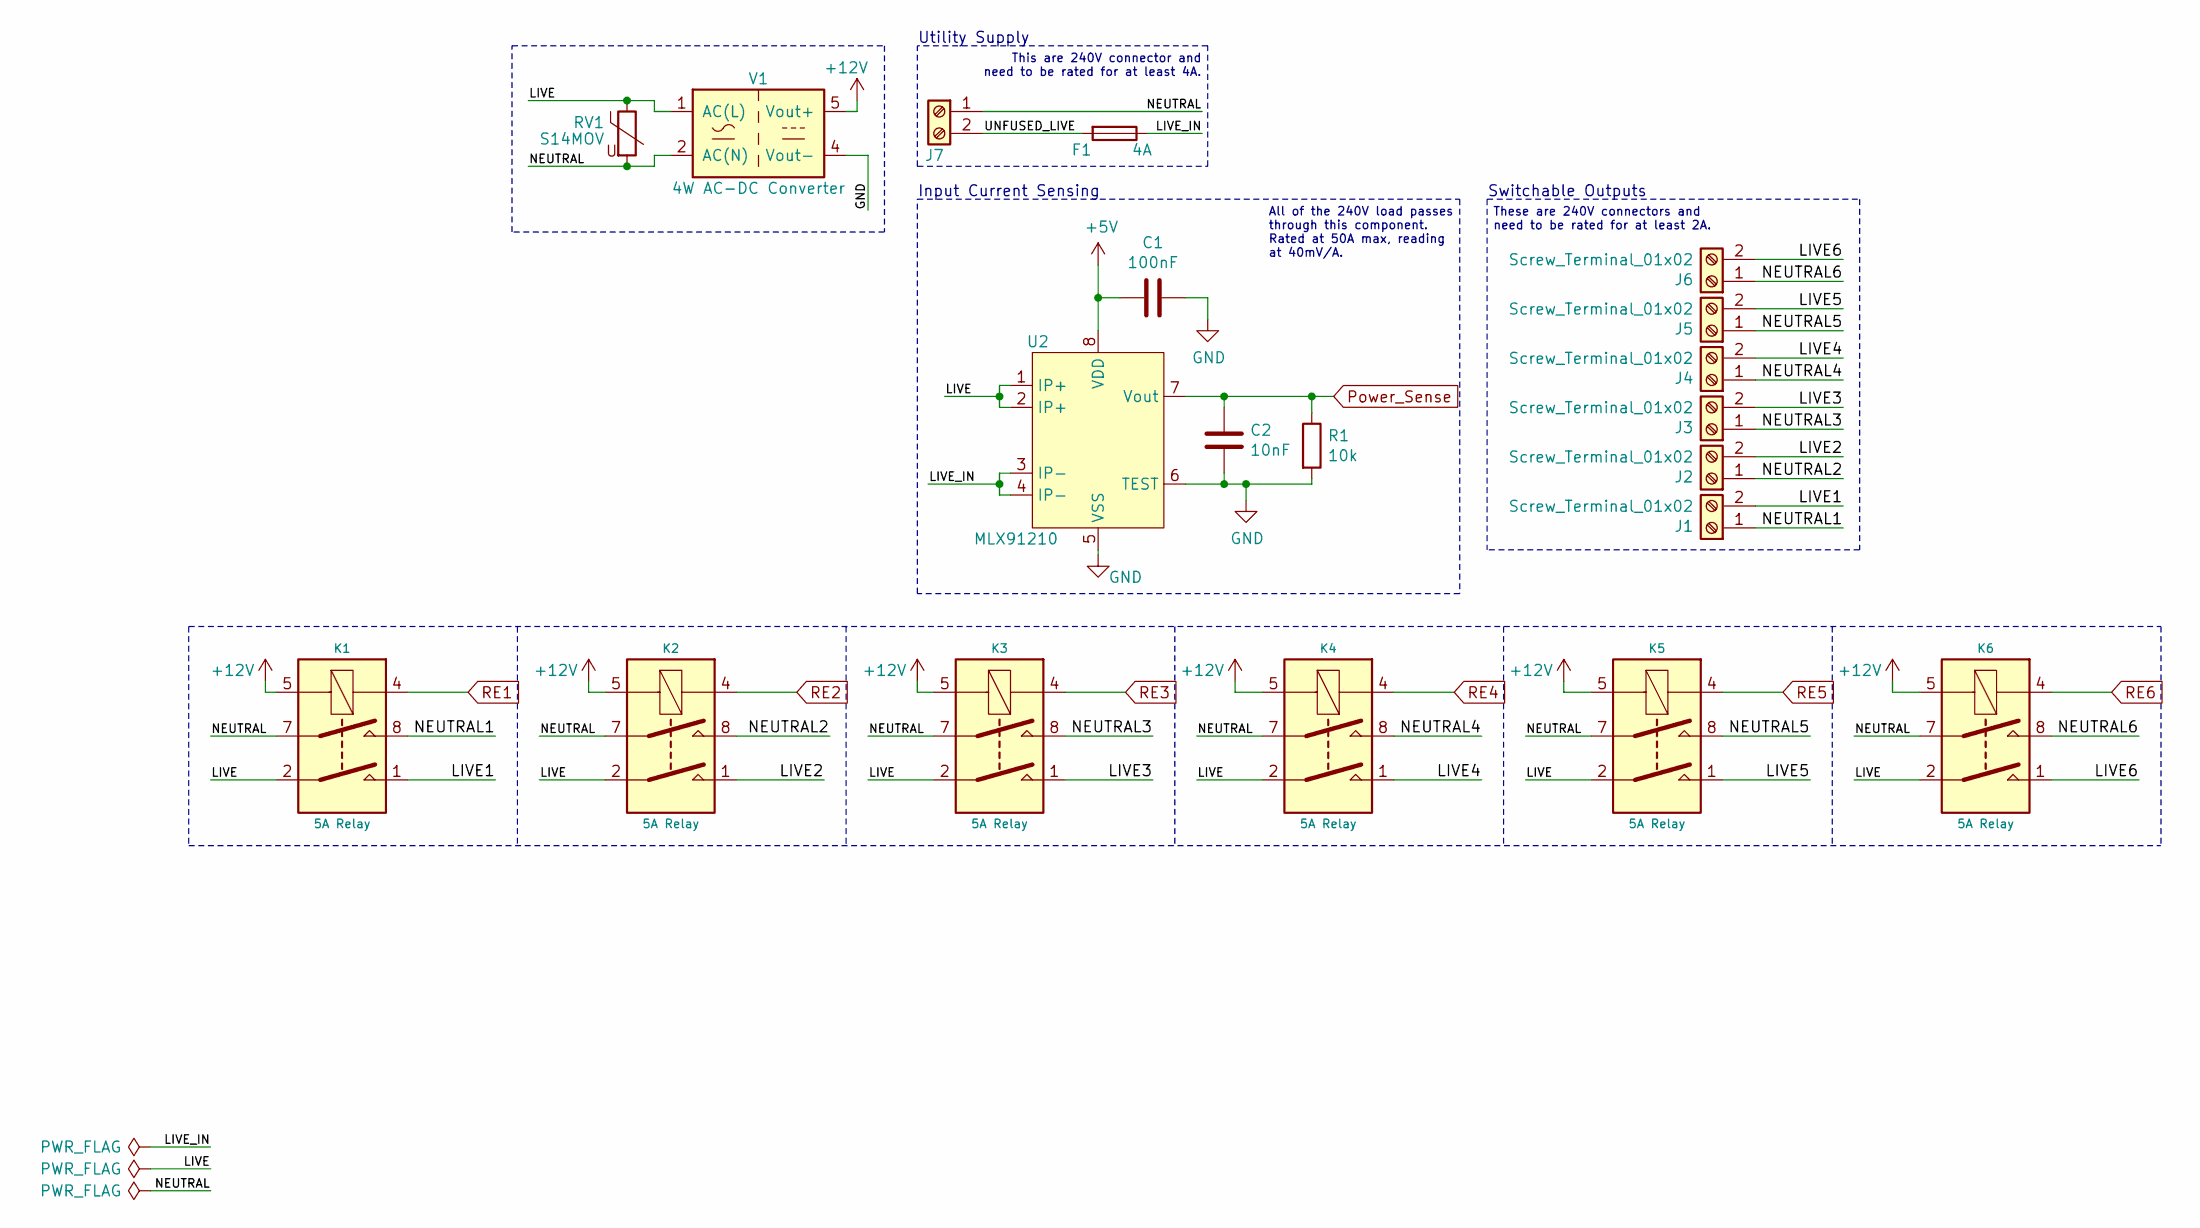
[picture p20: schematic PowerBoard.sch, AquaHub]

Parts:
C1: 100nF; C_0603_1608Metric_Pad1.05x0.95mm_HandSolder; Farnell CA07658
C2: 10nF; C_0603_1608Metric_Pad1.05x0.95mm_HandSolder; Mouser VJ0603A102GXAPW1BC
F1: 4A; Fuseholder_Glass_5mmx20mm; Mouser 534-3512
J1, J2, J3, J4, J5, J6, J7: Screw_Terminal_01x02; TerminalBlock_Phoenix_PT-1,5-2-5.0-H_1x02_P5.00mm_Horizontal; Mouser 1935161
K1, K2, K3, K4, K5, K6: 5A Relay; Relay_DPST_Fujitsu_FTR-F1A; Mouser FTR-F1AA012V
R1: 10k; R_0603_1608Metric_Pad1.05x0.95mm_HandSolder; Mouser 603-RC0603FR-0710KL
RV1: S14MOV; RV_Disc_D15.5mm_W6.1mm_P7.5mm; Mouser B72214P2251K101
U2: MLX91210; SOIC-8_3.9x4.9mm_P1.27mm; Mouser MLX91210KDC-CAS-102-SP
V1: 4W AC-DC Converter; Converter_ACDC_RECOM_RAC04-xxSGx_THT; Mouser RAC04-12SGB

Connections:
+5V: C1.2, U2.8 (VDD); also elsewhere on the board
+12V: K1.5, K2.5, K3.5, K4.5, K5.5, K6.5, V1.5 (Vout+); also elsewhere on the board
/PowerBoard/LIVE: K1.2, K2.2, K3.2, K4.2, K5.2, K6.2, RV1.1, U2.1 (IP+), U2.2 (IP+), V1.1 (AC(L))
/PowerBoard/LIVE1: J1.2, K1.1
/PowerBoard/LIVE2: J2.2, K2.1
/PowerBoard/LIVE3: J3.2, K3.1
/PowerBoard/LIVE4: J4.2, K4.1
/PowerBoard/LIVE5: J5.2, K5.1
/PowerBoard/LIVE6: J6.2, K6.1
/PowerBoard/LIVE_IN: F1.1, U2.3 (IP-), U2.4 (IP-)
/PowerBoard/NEUTRAL: J7.1, K1.7, K2.7, K3.7, K4.7, K5.7, K6.7, RV1.2, V1.2 (AC(N))
/PowerBoard/NEUTRAL1: J1.1, K1.8
/PowerBoard/NEUTRAL2: J2.1, K2.8
/PowerBoard/NEUTRAL3: J3.1, K3.8
/PowerBoard/NEUTRAL4: J4.1, K4.8
/PowerBoard/NEUTRAL5: J5.1, K5.8
/PowerBoard/NEUTRAL6: J6.1, K6.8
/PowerBoard/UNFUSED_LIVE: F1.2, J7.2
GND: C1.1, C2.2, R1.2, U2.5 (VSS), U2.6 (TEST), V1.4 (Vout-); also elsewhere on the board
Power_Sense: C2.1, R1.1, U2.7 (Vout); also elsewhere on the board
RE1: K1.4; also elsewhere on the board
RE2: K2.4; also elsewhere on the board
RE3: K3.4; also elsewhere on the board
RE4: K4.4; also elsewhere on the board
RE5: K5.4; also elsewhere on the board
RE6: K6.4; also elsewhere on the board

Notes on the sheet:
Switchable Outputs
These are 240V connectors and need to be rated for at least 2A.
Utility Supply
This are 240V connector and need to be rated for at least 4A.
Input Current Sensing
All of the 240V load passes through this component. Rated at 50A max, reading at 40mV/A.

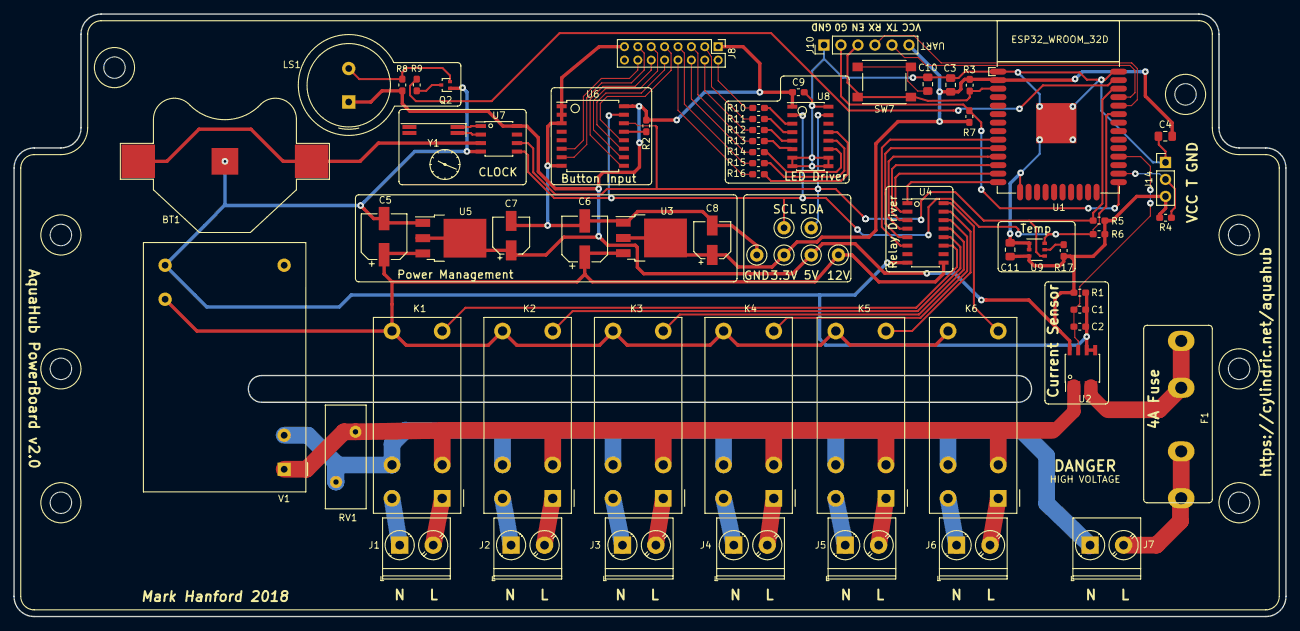
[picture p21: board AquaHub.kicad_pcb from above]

Board: 2 copper layers, 190.0 x 90.0 mm, 75 parts (0 on the bottom side), 69 nets.

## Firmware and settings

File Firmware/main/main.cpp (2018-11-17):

/*
Copyright 2018 Mark Hanford and AquaHub contributors.

Licensed under the Apache License, Version 2.0 (the "License");
you may not use this file except in compliance with the License.
You may obtain a copy of the License at

    http://www.apache.org/licenses/LICENSE-2.0

Unless required by applicable law or agreed to in writing, software
distributed under the License is distributed on an "AS IS" BASIS,
WITHOUT WARRANTIES OR CONDITIONS OF ANY KIND, either express or implied.
See the License for the specific language governing permissions and
limitations under the License.
*/

#include "Arduino.h"
#include <Wire.h>
#include <WiFi.h>

// Local includes
#include "RelayControl.h"
#include "LedControl.h"
#include "TimeControl.h"
#include "WebControl.h"
#include "WifiControl.h"

void scan_i2c();

// Wifi setup
String sids[3]      = { "ChocolateCows", "SHM",          "Guest" };
String passwords[3] = { "CowsGoMoo",     "hackmeplease", "guestwifi" };

// I²C addresses
int RTC_I2C_ADDR = 0x68; // 1101000 = 104 = 0x68
int LED_I2C_ADDR = 0x60; // 1100000 =  96 = 0x60
int BTN_I2C_ADDR = 0x20; // 0100000 =  32 = 0x20

// Pins
int I2C_SCL   = SCL; // IO22, pin 36
int I2C_SDA   = SDA; // IO21, pin 33
int PWR_SENSE = 17;  // IO17, pin 28
int TMP_SENSE = 4;   // IO4,  pin 26
int SOUND_PIN = 23;  // IO23, pin 37
int SOUND_CHANNEL = 2;

uint8_t POW_PINS[NUM_RELAYS] = {33, 25, 26, 27, 14, 12}; // IO33=13, IO25=14, IO26=15, IO27=16, IO14=17, IO12=18

LedControl ledControl(Wire, LED_I2C_ADDR);
TimeControl timeControl(Wire, RTC_I2C_ADDR);
WebControl webControl;
WifiControl wifiControl;

char buffer [32];
int cnt = 0;
boolean ready = false;

void ParseLine() {
  char * strtokIndx;
  char delimiter[] = " \n";

  std::string command = "";
  std::string parameter = "";
  std::vector<std::string> parameters;

  
  // get the first element
  strtokIndx = strtok(buffer, delimiter);
  command.assign(strtokIndx, strlen(strtokIndx));
  Serial.print("Command received: [");
  Serial.print(command.c_str());
  Serial.println("]");
  strtokIndx = strtok(NULL, delimiter);

  while(strtokIndx != NULL) {
    parameter.assign(strtokIndx, strlen(strtokIndx));
    Serial.print("Parameter received: [");
    Serial.print(parameter.c_str());
    Serial.println("]");
    parameters.push_back(parameter);
    strtokIndx = strtok(NULL, delimiter);
  }


  if (command == "relay") {
    // Relay has further options, on or off
    if (parameters.at(0) == "on") {
      Relays.setState(atoi(parameters.at(1).c_str()), 1);
    } else if (parameters.at(0) == "off") {
      Relays.setState(atoi(parameters.at(1).c_str()), 0);
    } else if (parameters.at(0) == "get") {
      Relays.printStates();
    }
  } else if (command == "i2c") {
    // I2C just returns the current devices
    scan_i2c();
  } else if (command == "beep") {
    int value = atoi(parameters.at(0).c_str());
    uint32_t duty = (8191 / 255) * min(value, 255);
    Serial.print("Beeping "); Serial.print(value);
    Serial.print(" duty "); Serial.println(duty);
    ledcWrite(SOUND_CHANNEL, duty);
    delay(1000);
    ledcWrite(SOUND_CHANNEL, 0);
  } else if (command == "time") {
    if (parameters.at(0) == "get") {
      timeControl.printDate();
    } else if (parameters.at(0) == "set") {
      timeControl.setDate(3, 2, 1, 0, 3, 11, 18);
      timeControl.printDate();
    }
  }
}

void setup() {
  Serial.begin(115200);
  Wire.begin();
  
  scan_i2c();

  wifiControl.setup(sids, passwords);
  timeControl.setup();

  for (int i=0; i < NUM_RELAYS; i++)
  {
      Serial.print("Sending in #"); 
      Serial.print(i); 
      Serial.print(" on pin ");
      Serial.println(POW_PINS[i]);
  }


  Relays.setup(POW_PINS);
  ledControl.setup();
  webControl.setup();

  ledcSetup(SOUND_CHANNEL, 1000, 13);
  ledcAttachPin(SOUND_PIN, SOUND_CHANNEL);
}

void loop() {
  wifiControl.loop();
  timeControl.loop();
  Relays.loop();
  ledControl.loop();
  webControl.loop();


  if (ready)
  {
      ParseLine();
      ready = false;
  } else while (Serial.available())
  {
      char c = Serial.read();
      buffer[cnt++] = c;
      if ((c == '\n') || (cnt == sizeof(buffer)-1))
      {
          buffer[cnt] = '\0';
          cnt = 0;
          ready = true;
      }
  }
}



// A simple debugging aid that prints out the address of each detected I²C device.
void scan_i2c() {
  byte error, address;
  int nDevices;
  Serial.println("Scanning...");
  nDevices = 0;
  for(address = 1; address < 127; address++ ) {
    Wire.beginTransmission(address);
    error = Wire.endTransmission();
    if (error == 0) {
      Serial.print("I2C device found at address 0x");
      if (address < 16) {
        Serial.print("0");
      }
      Serial.println(address, HEX);
      nDevices++;
    }
    else if (error == 4) {
      Serial.print("Unknow error at address 0x");
      if (address < 16) {
        Serial.print("0");
      }
      Serial.println(address, HEX);
    }    
  }
  if (nDevices == 0) {
    Serial.println("\nNo I2C devices found\n");
  }
  else {
    Serial.println("\bdone\n");
  }    
}

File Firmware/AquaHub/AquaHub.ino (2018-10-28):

/*
Copyright 2018 Mark Hanford and AquaHub contributors.

Licensed under the Apache License, Version 2.0 (the "License");
you may not use this file except in compliance with the License.
You may obtain a copy of the License at

    http://www.apache.org/licenses/LICENSE-2.0

Unless required by applicable law or agreed to in writing, software
distributed under the License is distributed on an "AS IS" BASIS,
WITHOUT WARRANTIES OR CONDITIONS OF ANY KIND, either express or implied.
See the License for the specific language governing permissions and
limitations under the License.
*/

#include "Arduino.h"
#include <ArduinoOTA.h>
#include <Wire.h>
#include <WiFi.h>
#include <ESPmDNS.h>
#include <WiFiUdp.h>
#include <ArduinoOTA.h>

// Local includes
#include "RelayControl.h"
#include "LedControl.h"
#include "TimeControl.h"

// Wifi setup
const char* ssid = "ChocolateCows";
const char* password = "CowsGoMoo";

// 
int RTC_I2C_ADDR = 0x68; // 1101000
int LED_I2C_ADDR = 0x60; // 1100000
int BTN_I2C_ADDR = 0x20; // 0100000

// Pins
int I2C_SCL   = 36; // IO22, pin 36
int I2C_SDA   = 33; // IO21, pin 33
int PWR_SENSE = 28; // IO17, pin 28
int TMP_SENSE = 26; // IO4,  pin 26
int SOUND_PIN = 37; // IO23, pin 37

uint8_t POW_PINS[NUM_RELAYS] = {9, 10, 11, 12, 13, 14}; // IO33, IO25, IO26, IO27, IO14, IO12

RelayControl relayControl(POW_PINS);
LedControl ledControl(Wire, LED_I2C_ADDR);
TimeControl timeControl(Wire, RTC_I2C_ADDR);

void setup() {
  Serial.begin(115200);
  Wire.begin(I2C_SDA, I2C_SCL);
  
  scan_i2c();

  wifi_setup();
  timeControl.setup();
  relayControl.setup();
  ledControl.setup();
}

void loop() {
  ArduinoOTA.handle();
  timeControl.loop();
  relayControl.loop();
  ledControl.loop();
}

void wifi_setup() {
  Serial.println("Booting");
  WiFi.mode(WIFI_STA);
  WiFi.begin(ssid, password);
  while (WiFi.waitForConnectResult() != WL_CONNECTED) {
    Serial.println("Connection Failed! Rebooting...");
    delay(5000);
    ESP.restart();
  }

  // Port defaults to 3232
  // ArduinoOTA.setPort(3232);

  // Hostname defaults to esp3232-[MAC]
  // ArduinoOTA.setHostname("myesp32");

  // No authentication by default
  // ArduinoOTA.setPassword("admin");

  // Password can be set with it's md5 value as well
  // MD5(admin) = 21232f297a57a5a743894a0e4a801fc3
  // ArduinoOTA.setPasswordHash("21232f297a57a5a743894a0e4a801fc3");

  ArduinoOTA
    .onStart([]() {
      String type;
      if (ArduinoOTA.getCommand() == U_FLASH)
        type = "sketch";
      else // U_SPIFFS
        type = "filesystem";

      // NOTE: if updating SPIFFS this would be the place to unmount SPIFFS using SPIFFS.end()
      Serial.println("Start updating " + type);
    })
    .onEnd([]() {
      Serial.println("\nEnd");
    })
    .onProgress([](unsigned int progress, unsigned int total) {
      Serial.printf("Progress: %u%%\r", (progress / (total / 100)));
    })
    .onError([](ota_error_t error) {
      Serial.printf("Error[%u]: ", error);
      if (error == OTA_AUTH_ERROR) Serial.println("Auth Failed");
      else if (error == OTA_BEGIN_ERROR) Serial.println("Begin Failed");
      else if (error == OTA_CONNECT_ERROR) Serial.println("Connect Failed");
      else if (error == OTA_RECEIVE_ERROR) Serial.println("Receive Failed");
      else if (error == OTA_END_ERROR) Serial.println("End Failed");
    });

  ArduinoOTA.begin();

  Serial.println("Ready");
  Serial.print("IP address: ");
  Serial.println(WiFi.localIP());
}

void scan_i2c() {
  byte error, address;
  int nDevices;
  Serial.println("Scanning...");
  nDevices = 0;
  for(address = 1; address < 127; address++ ) {
    Wire.beginTransmission(address);
    error = Wire.endTransmission();
    if (error == 0) {
      Serial.print("I2C device found at address 0x");
      if (address < 16) {
        Serial.print("0");
      }
      Serial.println(address, HEX);
      nDevices++;
    }
    else if (error == 4) {
      Serial.print("Unknow error at address 0x");
      if (address < 16) {
        Serial.print("0");
      }
      Serial.println(address, HEX);
    }    
  }
  if (nDevices == 0) {
    Serial.println("No I2C devices found\n");
  }
  else {
    Serial.println("done\n");
  }    
}

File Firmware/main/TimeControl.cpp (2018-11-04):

/*
Copyright 2018 Mark Hanford and AquaHub contributors.

Licensed under the Apache License, Version 2.0 (the "License");
you may not use this file except in compliance with the License.
You may obtain a copy of the License at

    http://www.apache.org/licenses/LICENSE-2.0

Unless required by applicable law or agreed to in writing, software
distributed under the License is distributed on an "AS IS" BASIS,
WITHOUT WARRANTIES OR CONDITIONS OF ANY KIND, either express or implied.
See the License for the specific language governing permissions and
limitations under the License.
*/

#include <Arduino.h>
#include <Wire.h>
#include "TimeControl.h"


#define _DEBUG 1

TimeControl::TimeControl(TwoWire& wire, uint8_t address): _wire(wire)
{
    _address = address;
}

TimeControl::~TimeControl()
{
}

void TimeControl::setup()
{
    #if _DEBUG
    Serial.println("TimeControl starting up.");
    #endif

    setDate(3, 2, 1, 0, 3, 11, 18);
    printDate();
}

void TimeControl::loop()
{
}

void TimeControl::setDate(byte second, byte minute, byte hour, byte dayOfWeek, byte dayOfMonth, byte month, byte year)
{
    #if _DEBUG
    Serial.println("TimeControl setting the time.");
    #endif

    // sets time and date data to DS3231
    Wire.beginTransmission(_address);
    Wire.write(0); // set next input to start at the seconds register
    Wire.write(decToBcd(second)); // set seconds
    Wire.write(decToBcd(minute)); // set minutes
    Wire.write(decToBcd(hour)); // set hours
    Wire.write(decToBcd(dayOfWeek)); // set day of week (1=Sunday, 7=Saturday)
    Wire.write(decToBcd(dayOfMonth)); // set date (1 to 31)
    Wire.write(decToBcd(month)); // set month
    Wire.write(decToBcd(year)); // set year (0 to 99)
    Wire.endTransmission();
}

void TimeControl::getDate(
    byte *second,
    byte *minute,
    byte *hour,
    byte *dayOfWeek,
    byte *dayOfMonth,
    byte *month,
    byte *year)
{
    Wire.beginTransmission(_address);
    Wire.write(0);
    Wire.endTransmission();

    Wire.requestFrom(_address, (int)7);

    *second     = bcdToDec(Wire.read() & 0x7f);
    *minute     = bcdToDec(Wire.read());
    *hour       = bcdToDec(Wire.read() & 0x3f);  // Need to change this if 12 hour am/pm
    *dayOfWeek  = bcdToDec(Wire.read());
    *dayOfMonth = bcdToDec(Wire.read());
    *month      = bcdToDec(Wire.read());
    *year       = bcdToDec(Wire.read());
}

void TimeControl::printDate()
{
    byte second, minute, hour, dayOfWeek, dayOfMonth, month, year;

    Serial.println("Getting current time from the RTC...");
    getDate(&second, &minute, &hour, &dayOfWeek, &dayOfMonth, &month, &year);
    Serial.print(hour, DEC);
    Serial.print(":");
    Serial.print(minute, DEC);
    Serial.print(":");
    Serial.print(second, DEC);
    Serial.print("  ");
    Serial.print(month, DEC);
    Serial.print("/");
    Serial.print(dayOfMonth, DEC);
    Serial.print("/");
    Serial.print(year, DEC);
    Serial.print("  Day_of_week:");
    Serial.println(dayOfWeek, DEC);
}

// Convert binary coded decimal to normal decimal numbers
byte TimeControl::bcdToDec(byte val)
{
  return ( (val/16*10) + (val%16) );
}

byte TimeControl::decToBcd(byte val)
{
  return( (val/10*16) + (val%10) );
}

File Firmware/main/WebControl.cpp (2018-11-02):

/*
Copyright 2018 Mark Hanford and AquaHub contributors.

Licensed under the Apache License, Version 2.0 (the "License");
you may not use this file except in compliance with the License.
You may obtain a copy of the License at

    http://www.apache.org/licenses/LICENSE-2.0

Unless required by applicable law or agreed to in writing, software
distributed under the License is distributed on an "AS IS" BASIS,
WITHOUT WARRANTIES OR CONDITIONS OF ANY KIND, either express or implied.
See the License for the specific language governing permissions and
limitations under the License.
*/

#include <Arduino.h>
#include "SPIFFS.h"
#include "ESPAsyncWebServer.h"
#include "FS.h"

#include "WebControl.h"
#include "RelayControl.h"

#define _DEBUG 1
#ifndef FORMAT_SPIFFS_IF_FAILED 
#define FORMAT_SPIFFS_IF_FAILED false
#endif

WebControl::WebControl(): _server(WEBSERVER_PORT)
{
}

WebControl::~WebControl()
{
}

void WebControl::setup()
{
    #if _DEBUG
    Serial.println("WebControl starting up.");
    #endif

    if(!SPIFFS.begin(FORMAT_SPIFFS_IF_FAILED)){
        Serial.println("SPIFFS Mount Failed");
        return;
    }
    listDir(SPIFFS, "/", 0);

    _server.serveStatic("/", SPIFFS, "/");
    
    _server.on("/", HTTP_GET, [](AsyncWebServerRequest *request) {
        request->send(SPIFFS, "/index.html", "text/html");
    });

    _server.on("/relays", HTTP_GET, [this](AsyncWebServerRequest *request) {
        this->getRelayStatus(request);
    });

    _server.onNotFound([](AsyncWebServerRequest *request) {
        request->send(SPIFFS, "/404.html", "text/html");
    });

    _server.begin();
}

void WebControl::loop()
{
}


void WebControl::getRelayStatus(AsyncWebServerRequest *request)
{
    String message = "[";
    for (int i=0; i < NUM_RELAYS; i++)
    {
        message += "{\"id\": ";
        message += i;
        message += ", \"state\": ";
        message += Relays.getState(i);
        message += "}";
        if(i < NUM_RELAYS)
        {
            message += ",";
        }
    }
    message += "]";
    request->send(200, "text/json", message);
}


void WebControl::handleNotFound()
{
    // String message = "File Not Found\n\n";
    // message += "URI: ";
    // message += _server.uri();
    // message += "\nMethod: ";
    // message += (_server.method() == HTTP_GET) ? "GET" : "POST";
    // message += "\nArguments: ";
    // message += _server.args();
    // message += "\n";
    // for (uint8_t i = 0; i < _server.args(); i++) {
    //     message += " " + _server.argName(i) + ": " + _server.arg(i) + "\n";
    // }
    // #if _DEBUG
    // Serial.println(message);
    // #endif
    // _server.send(404, "text/plain", message);
}

void WebControl::listDir(fs::FS &fs, const char * dirname, uint8_t levels) 
{
    Serial.printf("Listing directory: %s\r\n", dirname);

    File root = fs.open(dirname);
    if(!root){
        Serial.println("- failed to open directory");
        return;
    }
    if(!root.isDirectory()){
        Serial.println(" - not a directory");
        return;
    }

    File file = root.openNextFile();
    while(file){
        if(file.isDirectory()){
            Serial.print("  DIR : ");
            Serial.println(file.name());
            if(levels){
                listDir(fs, file.name(), levels -1);
            }
        } else {
            Serial.print("  FILE: ");
            Serial.print(file.name());
            Serial.print("\tSIZE: ");
            Serial.println(file.size());
        }
        file = root.openNextFile();
    }
}

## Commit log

2018-09-09 Lots of new stuff
    [AquaHub.FCStd, AquaHub.kicad_pcb, AquaHub.sch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]
2018-09-10 Added OHL. Removed old board Step. Removed old outputs
    [AquaHub.step]
2018-09-10 Added latest output
    [AquaHub-B.Cu.gbr, AquaHub-B.Mask.gbr, AquaHub-B.Paste.gbr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]
2018-09-12 Auto-generated Outputs
    [AquaHub-B.Cu.gbr, AquaHub-B.Mask.gbr, AquaHub-B.Paste.gbr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]
2018-09-16 Many refinements
    [AquaHub.FCStd, AquaHub.kicad_pcb, AquaHub.sch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]
2018-09-17 Various changes
    [AquaHub-B_Cu.gbr, AquaHub-B_Fab.gbr, AquaHub-B_Mask.gbr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]
2018-09-30 Various updates and tweaks
    [AquaHub-B_Cu.gbr, AquaHub-B_Fab.gbr, AquaHub-B_Mask.gbr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]
2018-10-02 Updated for parts now in stdlib
    [AquaHub.kicad_pcb]
2018-10-04 Before trying a single-board
    [AquaHub.kicad_pcb, AquaHub.sch, FrontPanel.sch]
2018-10-14 Split different layout schemes
    [AquaHub-B_Cu.gbr, AquaHub-B_Fab.gbr, AquaHub-B_Mask.gbr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]
2018-10-15 New TwinBoard layout
    [AquaHub-B.Cu.gbr, AquaHub-B.Mask.gbr, AquaHub-B.Paste.gbr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]
2018-10-15 Removed old variants
    [AquaHub.kicad_pcb, AquaHub.sch, Compound.step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]
2018-10-19 Prep for first manufacturing run
    [AquaHub-B.Cu.gbl, AquaHub-B.Cu.gbr, AquaHub-B.Mask.gbr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]
2018-10-23 Firmware structure
    [AquaHub.kicad_pcb, AquaHub.sch]
2018-10-25 Switch the software license to Apache 2
2018-10-25 Trying newer arduino
2018-10-25 Adding ESP32
2018-10-25 Switch to IDF compile
2018-10-26 Switching to docker
2018-10-27 Commit latest hardware updates and initial firmware
    [AquaHub.kicad_pcb, AquaHub.sch, PowerBoard.sch]
2018-10-27 RelayControl framework
2018-10-27 Removed old BOM
2018-10-28 Initial LED control
2018-10-28 Some more framework
2018-10-30 Added some more framework
    [AquaHub.sch]
2018-10-31 Switched to IDF branch
2018-10-31 Basic web server framework
2018-11-02 Trying out the Vue framework
2018-11-04 Big PCB switch to a single board. Again.
    [AquaHub.kicad_pcb, AquaHub.sch, PowerBoard.sch]
2018-11-17 Finalising the Rev2 hardware.
    [AquaHub-B.Cu.gbl, AquaHub-B.Mask.gbs, AquaHub-B.SilkS.gbo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]
